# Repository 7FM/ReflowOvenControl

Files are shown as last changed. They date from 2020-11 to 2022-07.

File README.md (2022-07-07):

# ReflowOvenControl
This repo is a combination of the following great projects:
- https://github.com/dasaki/nanoReflowController
- https://github.com/0xPIT/reflowOvenController
- https://github.com/engineertype/Controleo3.git

with the focus of using the UI schemes of the first two projects and using the profile management & control algorithms from [Controleo3](https://www.whizoo.com/).

The whole project targets an Arduino Nano and therefore almost all used Libraries where optimized for space and sometimes for performance too.

## Profiles
As mentiened before this projects uses the Controleo Profile Management but with a reduced Token set (see: src/read_profiles.cpp or include/read_profiles.hpp).
A good overview for all tokens(also non supported ones) with explanation can be found [here](https://www.whizoo.com/profiles).

## Hardware
- Arduino Nano
- 1.8'' Color TFT display (ST7735R) as from Adafruit: https://www.adafruit.com/product/358 (can be replaced with serial UI only)
- Rotary Encoder (can be replaced with serial UI only)
- SD Card reader
- Thermocouple reader (MAX6675)
- Buzzer (optional)
- Servo (optional)
- SSR or something to control the oven
- oven to be controlled
- cooling fan (optional)
- convection fan (optional)

For convenience a custom PCB was created using [KiCad](https://www.kicad.org/) but is not mandatory.
Please note that I am no professional (resistors & transistor were arbitrarily chosen by own availability) so any use of the PCB at your own risk!
I also designed some 3D Models using [FreeCAD](https://www.freecadweb.org/) for mounting the hardware.

## Building
Clone the repository with `git clone --recursive` as submodules are used.
If already cloned, the submodules can also be downloaded afterwards using: `git submodule update --init --recursive`.
For compiling simply use [PlatformIO](https://platformio.org/).

## Configuration
Features, Pins & more can be configured in `src/config.h`. Feel free to ask if the impact of certain options is unclear.

## Useful ressources
- https://ww1.microchip.com/downloads/en/DeviceDoc/Atmel-7810-Automotive-Microcontrollers-ATmega328P_Datasheet.pdf
- https://academy.cba.mit.edu/classes/embedded_programming/doc1022.pdf
- http://ww1.microchip.com/downloads/en/DeviceDoc/Atmel-0856-AVR-Instruction-Set-Manual.pdf

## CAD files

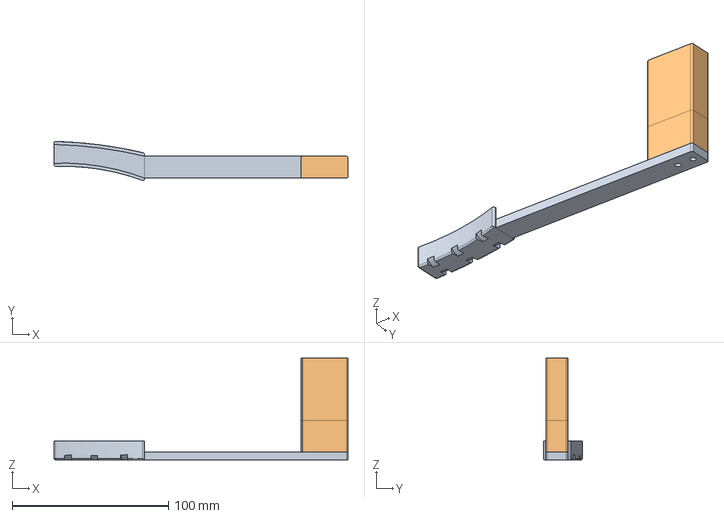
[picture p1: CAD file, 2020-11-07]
hardware/OvenHandleMount.FCStd
188.0 x 25.0 x 65.0 mm

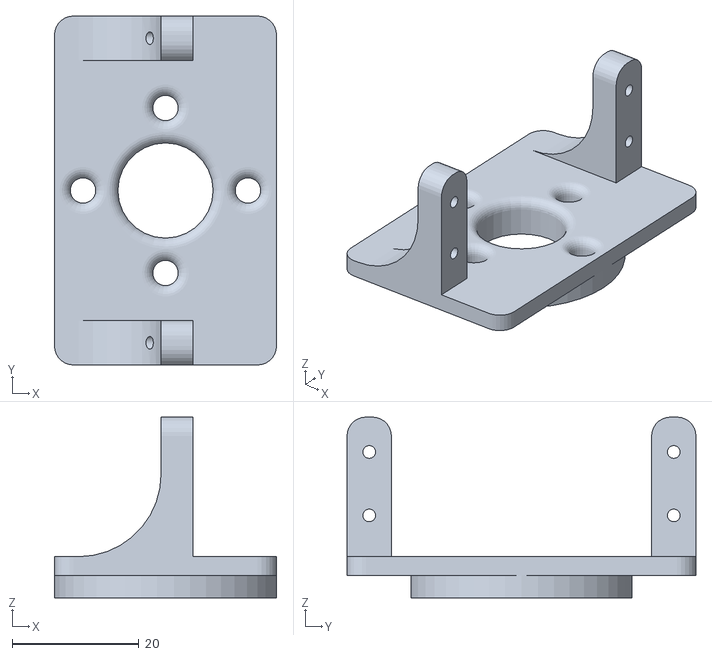
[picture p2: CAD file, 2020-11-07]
hardware/servoMountTest.stl
35.0 x 55.0 x 28.5

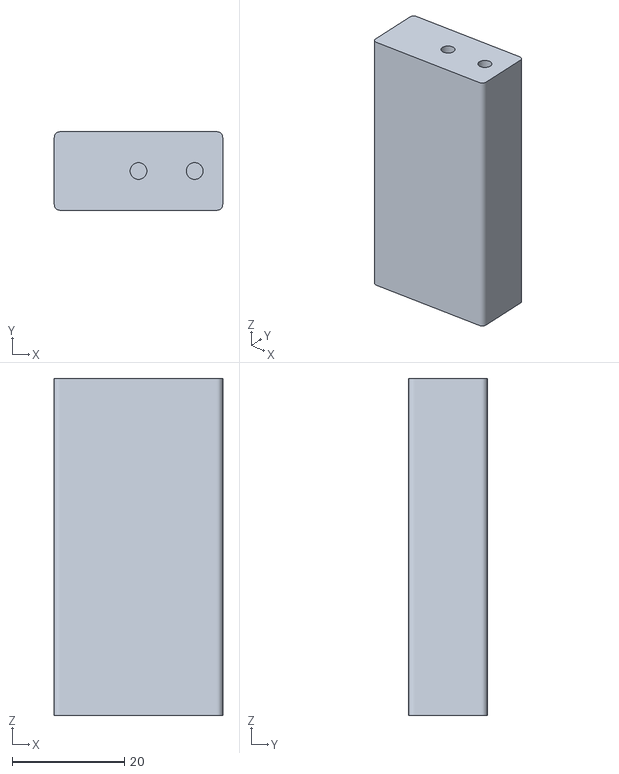
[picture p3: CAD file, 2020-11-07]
hardware/BadDesign.stl
30.0 x 14.0 x 60.0

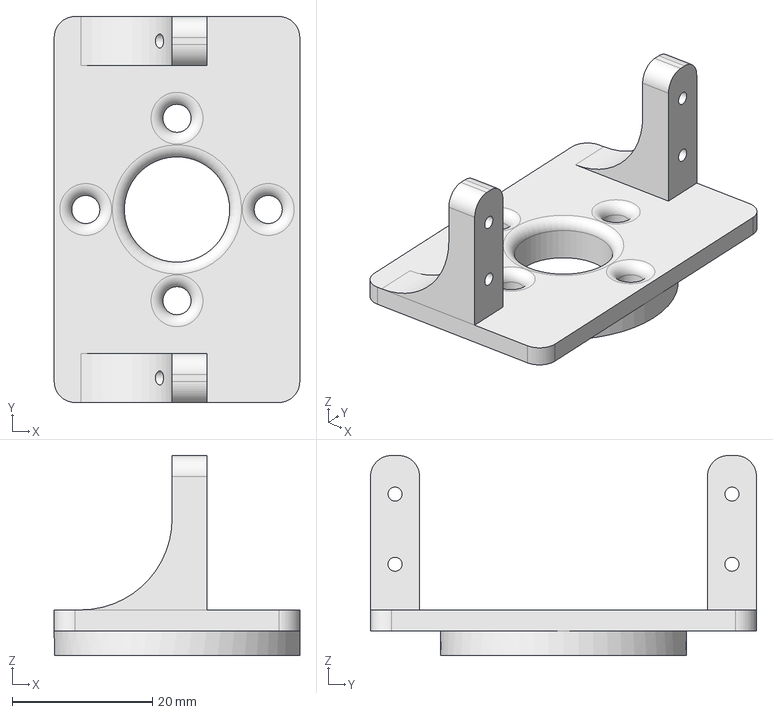
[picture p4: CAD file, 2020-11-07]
hardware/ServoMount.FCStd
35.0 x 55.0 x 28.5 mm

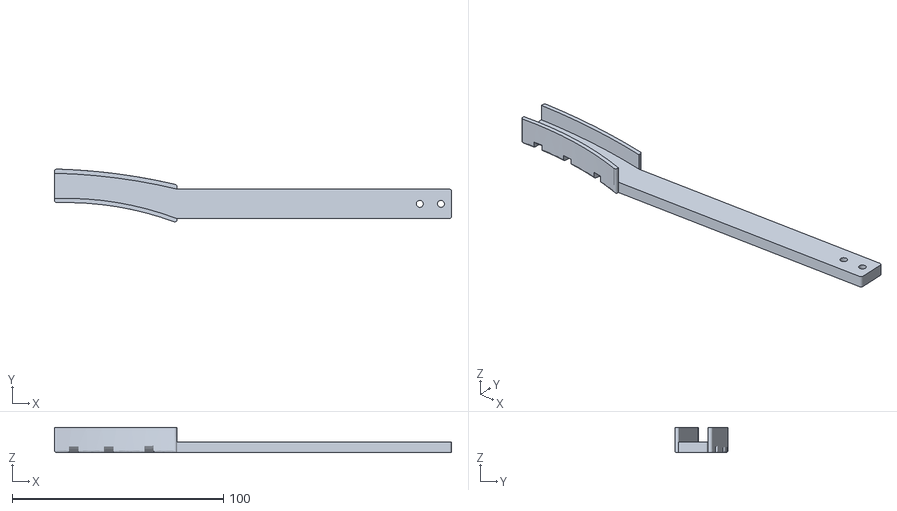
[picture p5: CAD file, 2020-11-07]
hardware/ovenHandleMountTest.stl
188.0 x 25.0 x 12.0

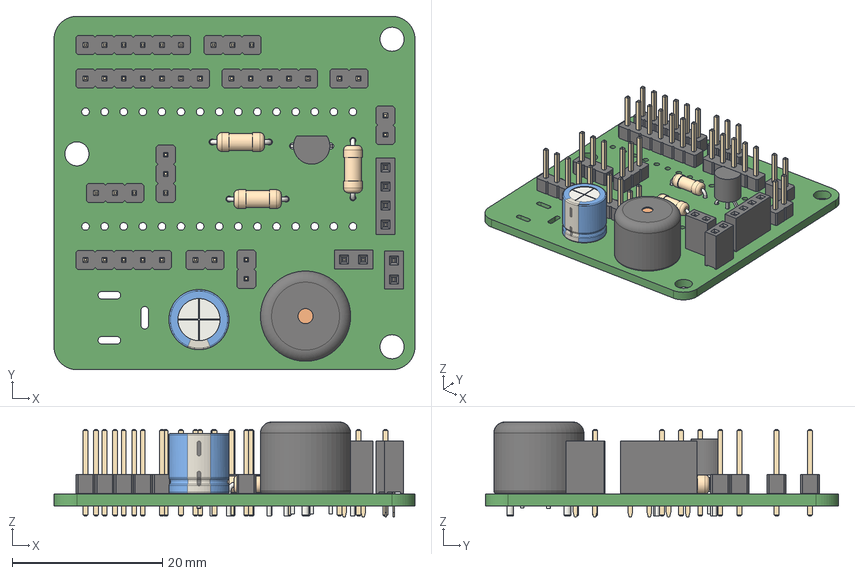
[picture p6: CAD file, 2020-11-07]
hardware/reflowOvenPCB.step
48.0 x 47.0 x 12.6 mm
Socket_header_Arduino_1x15 x 2

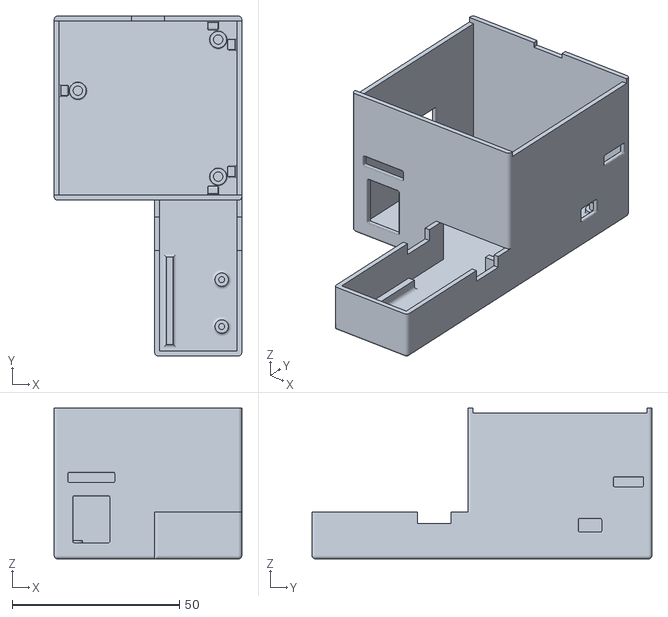
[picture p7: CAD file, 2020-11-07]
hardware/CaseBase.stl
56.0 x 101.5 x 45.0

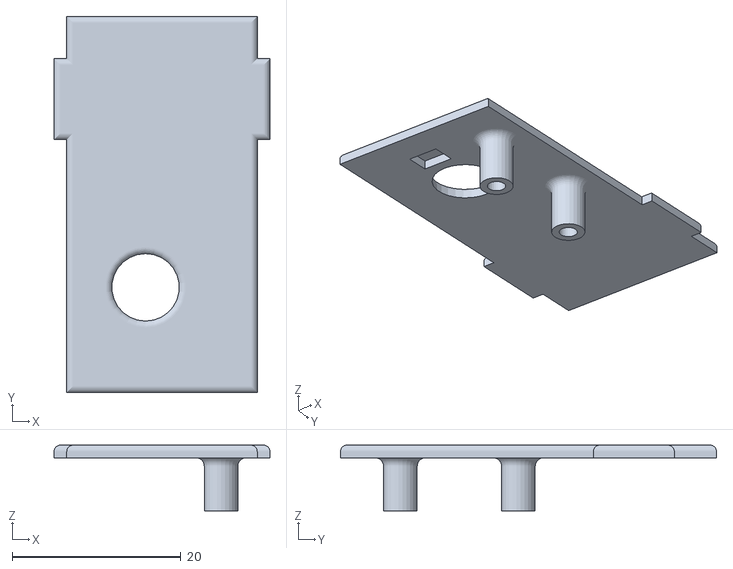
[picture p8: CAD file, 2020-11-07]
hardware/CaseBaseRotaryTop.stl
25.6 x 44.6 x 7.80

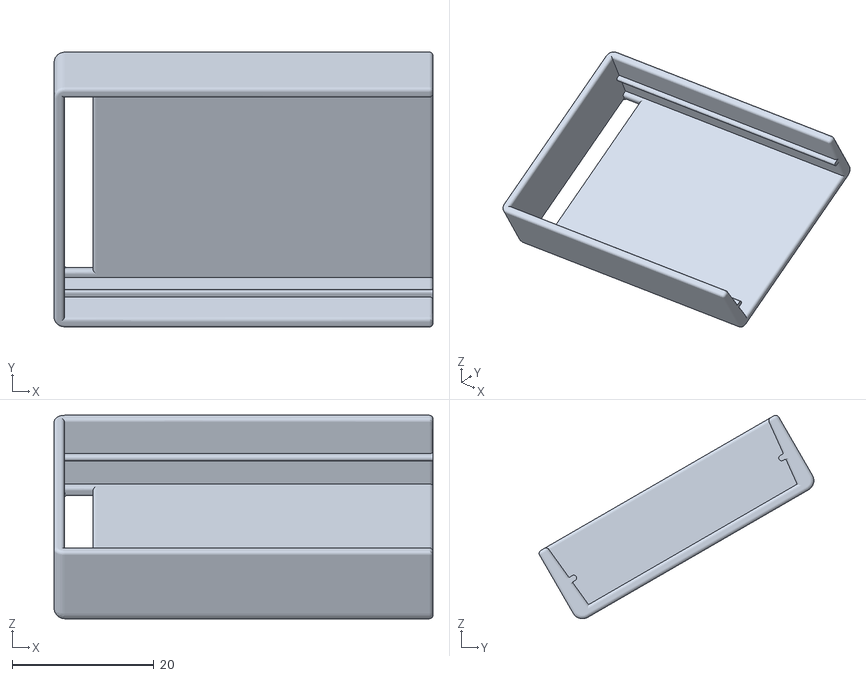
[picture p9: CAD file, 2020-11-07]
hardware/CaseDisplayMount.stl
53.5 x 38.8 x 28.7

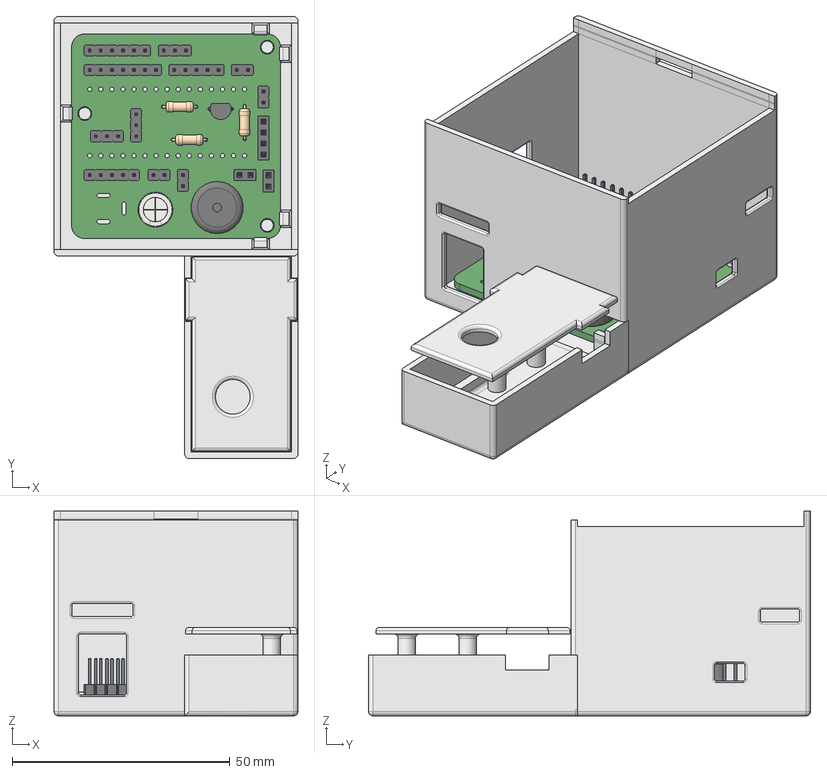
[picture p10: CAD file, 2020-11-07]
hardware/ReflowOvenCase.FCStd
56.0 x 101.5 x 47.0 mm
RotaryMount

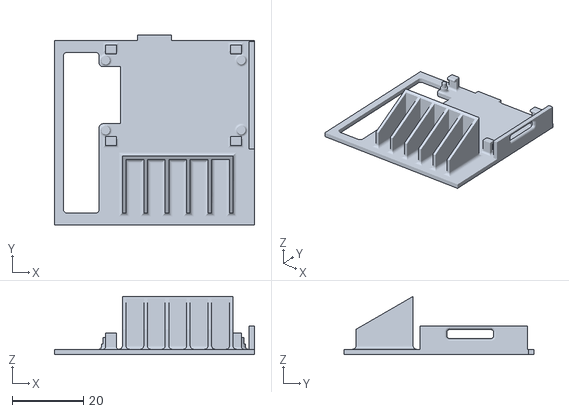
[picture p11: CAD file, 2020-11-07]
hardware/CaseTop.stl
56.0 x 53.1 x 16.3

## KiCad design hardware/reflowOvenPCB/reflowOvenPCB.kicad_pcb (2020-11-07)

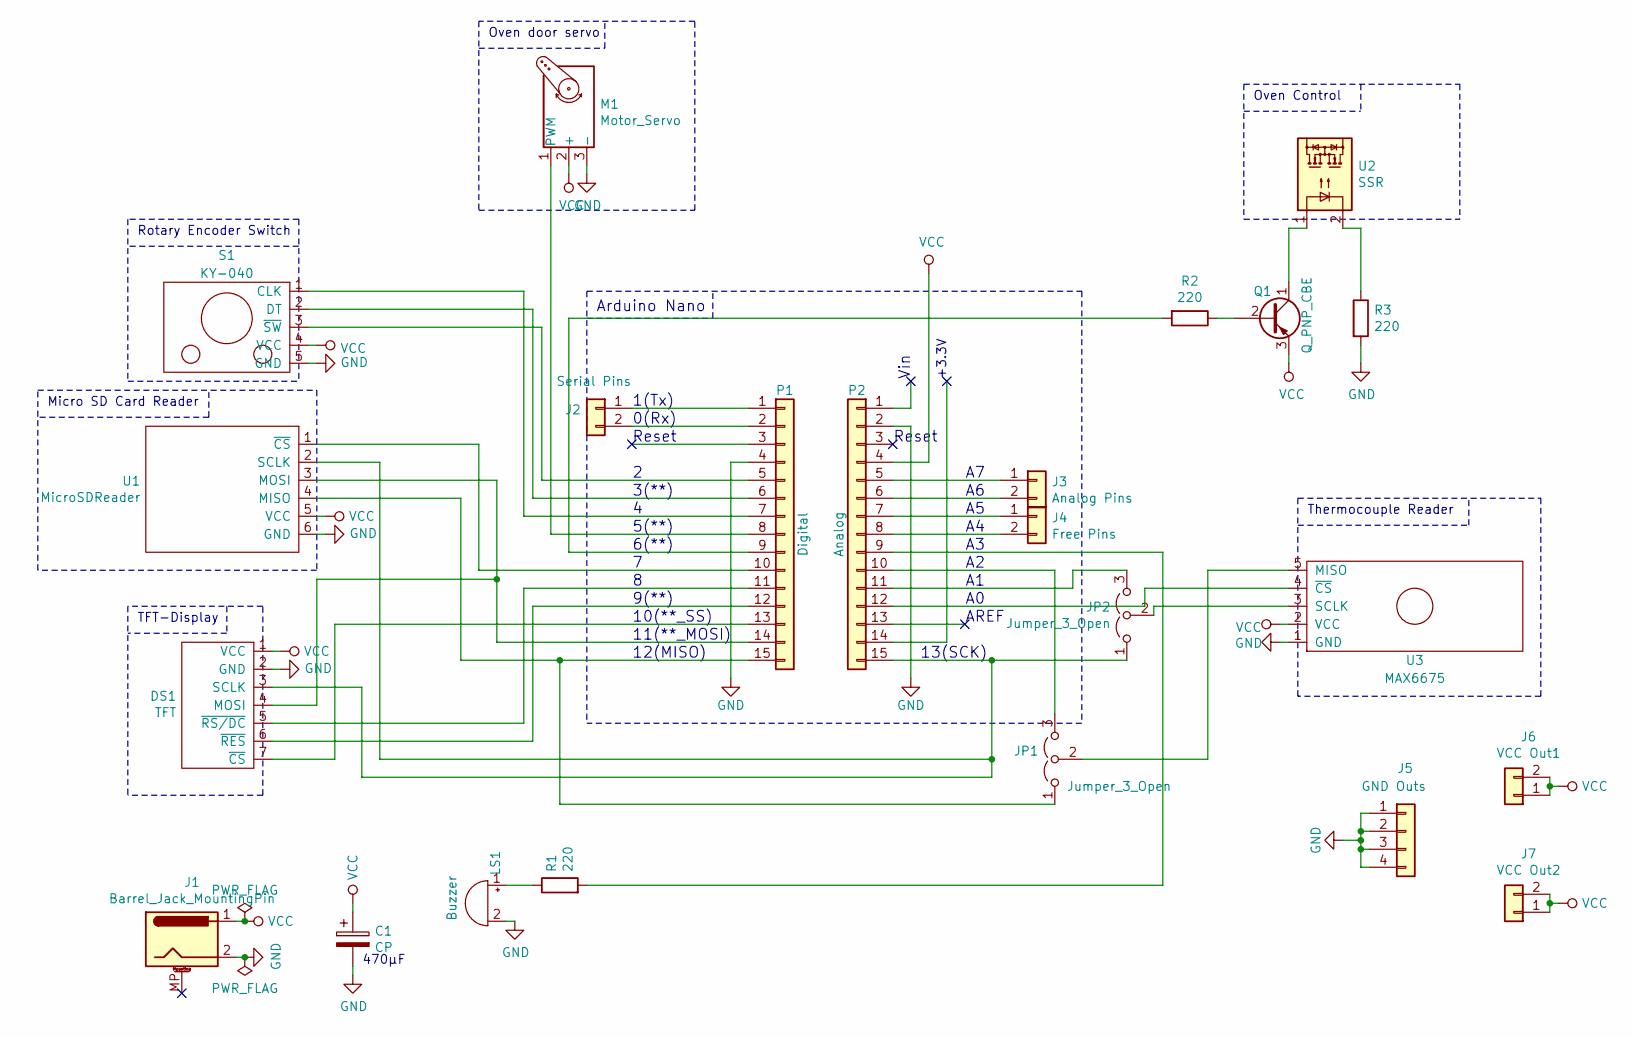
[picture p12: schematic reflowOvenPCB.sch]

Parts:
C1: CP; CP_Radial_D8.0mm_P3.50mm
DS1: TFT; PinHeader_1x07_P2.54mm_Vertical
J1: Barrel_Jack_MountingPin; BarrelJack_Horizontal
J2: Serial Pins; PinHeader_1x02_P2.54mm_Vertical
J3: Analog Pins; PinHeader_1x02_P2.54mm_Vertical
J4: Free Pins; PinHeader_1x02_P2.54mm_Vertical
J5: GND Outs; PinSocket_1x04_P2.54mm_Vertical
J6: VCC Out1; PinSocket_1x02_P2.54mm_Vertical
J7: VCC Out2; PinSocket_1x02_P2.54mm_Vertical
JP1, JP2: Jumper_3_Open; PinHeader_1x03_P2.54mm_Vertical
LS1: Buzzer; Buzzer_12x9.5RM7.6
M1: Motor_Servo; PinHeader_1x03_P2.54mm_Vertical
P1: Digital; Socket_Strip_Arduino_1x15
P2: Analog; Socket_Strip_Arduino_1x15
Q1: Q_PNP_CBE; TO-92_Inline_Wide
R1, R2, R3: 220; R_Axial_DIN0207_L6.3mm_D2.5mm_P7.62mm_Horizontal
S1: KY-040; PinHeader_1x05_P2.54mm_Vertical
U1: MicroSDReader; PinHeader_1x06_P2.54mm_Vertical
U2: SSR; PinHeader_1x02_P2.54mm_Vertical
U3: MAX6675; PinHeader_1x05_P2.54mm_Vertical

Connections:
GND: C1.2, DS1.2 (GND), J1.2, J5.1, J5.2, J5.3, J5.4, LS1.2 (+), M1.3 (-), P1.4, P2.2, R3.2, S1.5 (GND), U1.6 (GND), U3.1 (GND)
unnamed: DS1.3 (SCLK), JP2.1 (A), P2.15, U1.2 (SCLK)
unnamed: DS1.4 (MOSI), P1.14, U1.3 (MOSI)
unnamed: DS1.5 (~RS/DC), P1.11
unnamed: DS1.6 (~RES), P1.12
unnamed: DS1.7 (~CS), P1.13
unnamed: J2.1, P1.1
unnamed: J2.2, P1.2
unnamed: J3.1, P2.5
unnamed: J3.2, P2.6
unnamed: J4.1, P2.7
unnamed: J4.2, P2.8
unnamed: JP1.1 (A), P1.15, U1.4 (MISO)
unnamed: JP1.2 (C), U3.5 (MISO)
unnamed: JP1.3 (B), P2.10
unnamed: JP2.2 (C), U3.3 (SCLK)
unnamed: JP2.3 (B), P2.11
unnamed: LS1.1 (-), R1.1
unnamed: M1.1 (PWM), P1.8
unnamed: P1.5, S1.3 (~SW)
unnamed: P1.6, S1.2 (DT)
unnamed: P1.7, S1.1 (CLK)
unnamed: P1.9, R2.2
unnamed: P1.10, U1.1 (~CS)
unnamed: P2.9, R1.2
unnamed: P2.12, U3.4 (~CS)
unnamed: Q1.1 (C), U2.1
unnamed: Q1.2 (B), R2.1
unnamed: R3.1, U2.2
VCC: C1.1, DS1.1 (VCC), J1.1, J6.1, J6.2, J7.1, J7.2, M1.2 (+), P2.4, Q1.3 (E), S1.4 (VCC), U1.5 (VCC), U3.2 (VCC)

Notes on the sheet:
Arduino Nano
Rotary Encoder Switch
TFT-Display
Oven Control
Oven door servo
Micro SD Card Reader
Thermocouple Reader
Reset
0(Rx)
1(Tx)
AREF
11(**_MOSI)
12(MISO)
10(**_SS)
9(**)
6(**)
5(**)
3(**)
13(SCK)
Vin
+3.3V
470µF

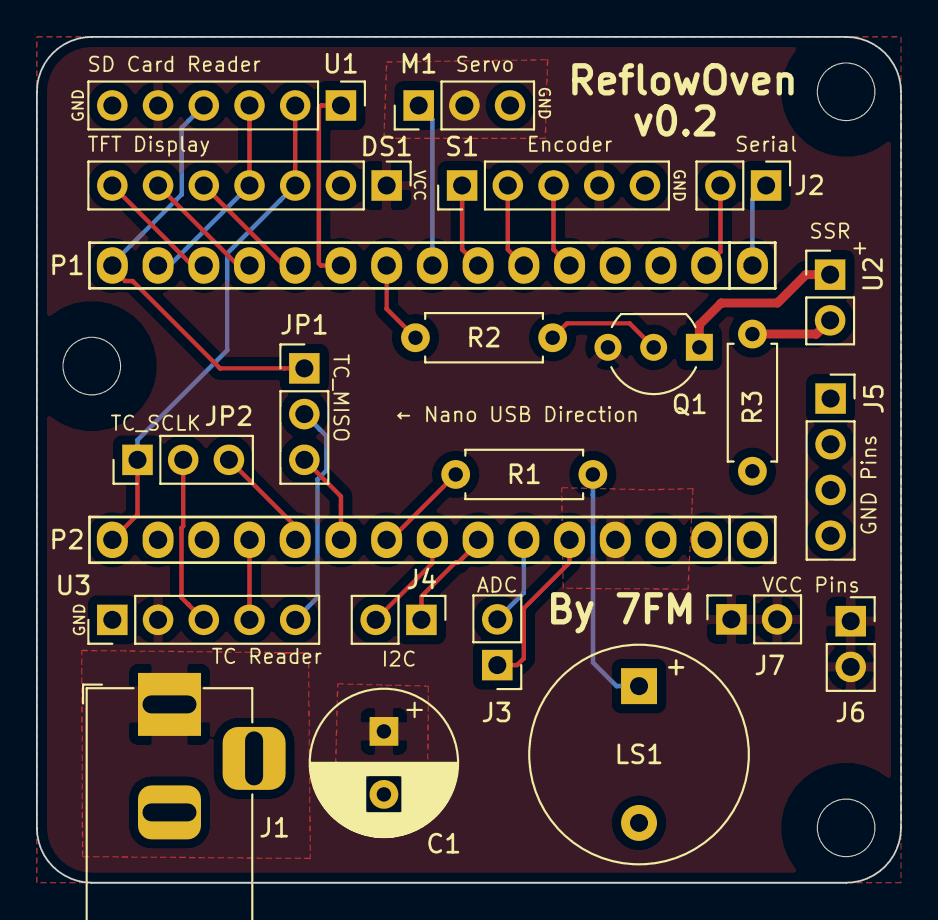
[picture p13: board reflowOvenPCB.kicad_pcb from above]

Board: 2 copper layers, 48.0 x 47.0 mm, 23 parts (0 on the bottom side), 30 nets.

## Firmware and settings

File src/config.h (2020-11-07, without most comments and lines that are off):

#pragma once
#include <stdint.h>
#define REFLOW_FEATURE
#define LEARNING_FEATURE
#define EEPROM_SETTINGS_FEATURE
#define SD_SETTINGS_FEATURE
#define PREF_SETTINGS
#define OUTPUT_SETTINGS
#define PROFILE_ARRAY
#define PROFILE_ARRAY_SIZE 10
#define USE_BUZZER
#define NEWTONE_USE_TIMER2
#define BUZZER_SOUNDTRACKS
#define USE_SDFAT
#ifdef __AVR
#define PIN_OPTIMIZATIONS
#endif
#define USE_DISPLAY
#define ENCODER_STEPS_PER_NOTCH 4
#define ENCODER_IS_ACTIVE false
#define ENCODER_ACCEL_TOP 3072 // max. acceleration: *12 (val >> 8)
#define SERVO_SUPPORT
#define SERVO_SETTINGS
#define SERVO_DEFAULT_OPEN_DEGREES 90
#define SERVO_DEFAULT_CLOSE_DEGREES 90
#define SERVO_DEFAULT_MIN_PULSE_WIDTH 1000
#define SERVO_DEFAULT_MAX_PULSE_WIDTH 2000
#define DEFAULT_LEARNED_POWER 13
#define DEFAULT_LEARNED_INERTIA 41
#define DEFAULT_LEARNED_INSULATION 124
#define DEFAULT_REFLOW_BOTTOM_ELEMENT_MAX_DUTY 100
#define DEFAULT_REFLOW_TOP_ELEMENT_MAX_DUTY 75
#define DEFAULT_REFLOW_BOOST_ELEMENT_MAX_DUTY 65
#define DEFAULT_REFLOW_BOTTOM_ELEMENT_BIAS 100
#define DEFAULT_REFLOW_TOP_ELEMENT_BIAS 80
#define DEFAULT_REFLOW_BOOST_ELEMENT_BIAS 50
#define DEFAULT_REFLOW_MAX_TEMP 260
#define DEFAULT_REFLOW_MAX_DEVIATION 20
#if defined(USE_DISPLAY) && !defined(DEBUG)
#define DISABLE_SERIAL
#endif
#if defined(BUZZER_SOUNDTRACKS) && !defined(BUZZER_SOUNDTRACKS_NOT_RANDOM)
#define RANDOM_INIT_ANALOG_PIN A7
#endif
#define SSR_EN_PIN 6
#define SSR_EN_INVERSE_LOGIC
#define THERMO_SO A2
#define THERMO_CS A0
#define THERMO_CLK A1
#define THERMO_VCC_PIN -1
#define THERMO_GND_PIN -1
#define THERMO_SAMPLE_DELAY 250
#define BUZZER_PIN A3
#define BUZZER_GND_PIN -1
#define SERVO_PIN 5
#define TFT_CS 10 // TFT select pin
#define SD_CS 7   // SD card select pin
#define TFT_DC 8  // TFT display/command pin
#define TFT_RST 9 // Or set to -1 and connect to Arduino RESET pin
#define ENCODER_B_PIN 4
#define ENCODER_A_PIN 3
#define ENCODER_SW_PIN 2
#define ENCODER_VCC_PIN -1
#define ENCODER_GND_PIN -1
#define NEWTONE_STATIC_PIN BUZZER_PIN
#if defined(SERVO_SUPPORT) && !defined(NEWTONE_USE_TIMER2)
#define NEWTONE_USE_TIMER2
#endif
#define SAVE_DELAYS
#define ROTARY_ISR_SERVICE
#define SPLIT_ROTARY_ISR_SERVICE
#define DEBOUNCE_TIME 0
#define ROTARY_ACCEL_OPTIMIZATION
#define ENCODER_ACCEL_INC 10
#define ENCODER_ACCEL_DEC 30
#define MAX6675_USE_FIX_PT
#define _GET_PIN_INTERRUPT_LINE(pin) ((pin) <= 7 ? 2 : (pin) <= 15 ? 0 : 1)
#define _CAN_PIN_USE_INTX_INTERRUPT_LINE(pin) ((pin) == 2 || (pin) == 3)
#if _CAN_PIN_USE_INTX_INTERRUPT_LINE(ENCODER_A_PIN) || _CAN_PIN_USE_INTX_INTERRUPT_LINE(ENCODER_B_PIN) || _GET_PIN_INTERRUPT_LINE(ENCODER_A_PIN) != _GET_PIN_INTERRUPT_LINE(ENCODER_B_PIN)
#define ENCODER_PINS_USE_DIFFERENT_LINES
#endif
#if defined(USE_DISPLAY) && defined(ROTARY_ISR_SERVICE) && defined(SPLIT_ROTARY_ISR_SERVICE) && !defined(ENCODER_PINS_USE_DIFFERENT_LINES)
#error "SPLIT_ROTARY_ISR_SERVICE is not possible if ENCODER_A_PIN and ENCODER_B_PIN share the same interrupt vector!"
#endif
#if _CAN_PIN_USE_INTX_INTERRUPT_LINE(ENCODER_A_PIN)
#if ENCODER_A_PIN == 2
#define ENCODER_A_PIN_ISR_VECTOR INT0_vect
#else
#define ENCODER_A_PIN_ISR_VECTOR INT1_vect
#endif
#else
#if _GET_PIN_INTERRUPT_LINE(ENCODER_A_PIN) == 2
#define ENCODER_A_PIN_ISR_VECTOR PCINT2_vect
#elif _GET_PIN_INTERRUPT_LINE(ENCODER_A_PIN) == 1
#define ENCODER_A_PIN_ISR_VECTOR PCINT1_vect
#elif _GET_PIN_INTERRUPT_LINE(ENCODER_A_PIN) == 0
#define ENCODER_A_PIN_ISR_VECTOR PCINT0_vect
#else
#error "Can not determine interrupt vector for ENCODER_A_PIN"
#endif
#endif
#if _CAN_PIN_USE_INTX_INTERRUPT_LINE(ENCODER_B_PIN)
#if ENCODER_B_PIN == 2
#define ENCODER_B_PIN_ISR_VECTOR INT0_vect
#else
#define ENCODER_B_PIN_ISR_VECTOR INT1_vect
#endif
#else
#if _GET_PIN_INTERRUPT_LINE(ENCODER_B_PIN) == 2
#define ENCODER_B_PIN_ISR_VECTOR PCINT2_vect
#elif _GET_PIN_INTERRUPT_LINE(ENCODER_B_PIN) == 1
#define ENCODER_B_PIN_ISR_VECTOR PCINT1_vect
#elif _GET_PIN_INTERRUPT_LINE(ENCODER_B_PIN) == 0
#define ENCODER_B_PIN_ISR_VECTOR PCINT0_vect
#else
#error "Can not determine interrupt vector for ENCODER_B_PIN"
#endif
#endif

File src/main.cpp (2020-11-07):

#include "config.h"
#include <Arduino.h>
#include <FastPin.h>
#include <stdint.h>

#include "display.hpp"
#include "menu.hpp"
#include "prefs.hpp"
#include "progmem_strings.hpp"
#include "watchdog_abuse.hpp"

#if defined(REFLOW_FEATURE) || defined(SD_SETTINGS_FEATURE) || (defined(USE_BUZZER) && defined(BUZZER_TRACKS_FROM_SD))
#include "sd_wrapper.hpp"
#endif

#if defined(REFLOW_FEATURE) || defined(LEARNING_FEATURE)
#include "outputs.hpp"
#include "thermo.hpp"
#endif

#ifdef REFLOW_FEATURE
#include "profile.hpp"
#include "read_profiles.hpp"
#include "reflow.hpp"
#endif

#ifdef USE_BUZZER
#include "buzzer.hpp"
#endif

#ifdef SERVO_SUPPORT
#include "servo.hpp"
#endif

#ifdef LEARNING_FEATURE
#include "learn.hpp"
#endif

void setup() {
    SERIALbegin(9600);

#ifdef USE_BUZZER
    initBuzzer();
#endif

#if defined(REFLOW_FEATURE) || defined(LEARNING_FEATURE)
    initThermo();
    initOutputs();
#endif

#ifdef SERVO_SUPPORT
    initServo();
#endif

#ifdef USE_DISPLAY
#ifdef SD_CS
    // We need to be sure that the devices that share the SPI bus are disabled!
    FastPin<SD_CS>::setOutput();
    FastPin<SD_CS>::hi();
#endif
#endif

    initDisplay();

#if defined(REFLOW_FEATURE) || defined(SD_SETTINGS_FEATURE) || (defined(USE_BUZZER) && defined(BUZZER_TRACKS_FROM_SD))
    if (!initSD()) {
        // Stay here forever
        for (;;) {
        }
    }
#endif

#ifdef REFLOW_FEATURE
    initProfiles();
#endif

    // Get the stored preferences
    getPrefs();

    // wait for MAX6675 chip to stabilize
    _delay_ms(500);

    // Finally initialize watchdog abuse as its ISR contains routines which require that everything is setup!
    initWatchdogAbuse();
}

static Menu::Engine renderEngine(Menu::Engine::getChild(&miExit));

void loop() {
    showMenu(renderEngine, &miExit);
}

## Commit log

2020-11-07 add kicad project & freecad designes
    [BadDesign.stl, CaseBase.stl, CaseBaseRotaryTop.stl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]
2020-12-07 Remove unsave optimization flag
    See: https://github.com/MarlinFirmware/Marlin/pull/20389
